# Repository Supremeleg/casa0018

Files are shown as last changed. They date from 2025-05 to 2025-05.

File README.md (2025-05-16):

# GlyphWand – TinyML Gesture Recognition Wand
This project uses a simple magic wand to write ‘magic spells’ in the air to control the colour and brightness of the light strips of a smart cabin clock simulated by LEGO.
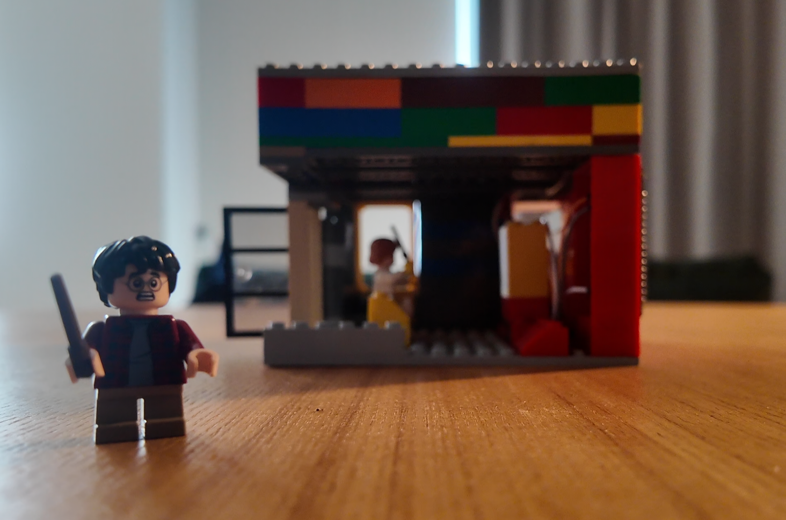
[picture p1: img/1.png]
Wand in action
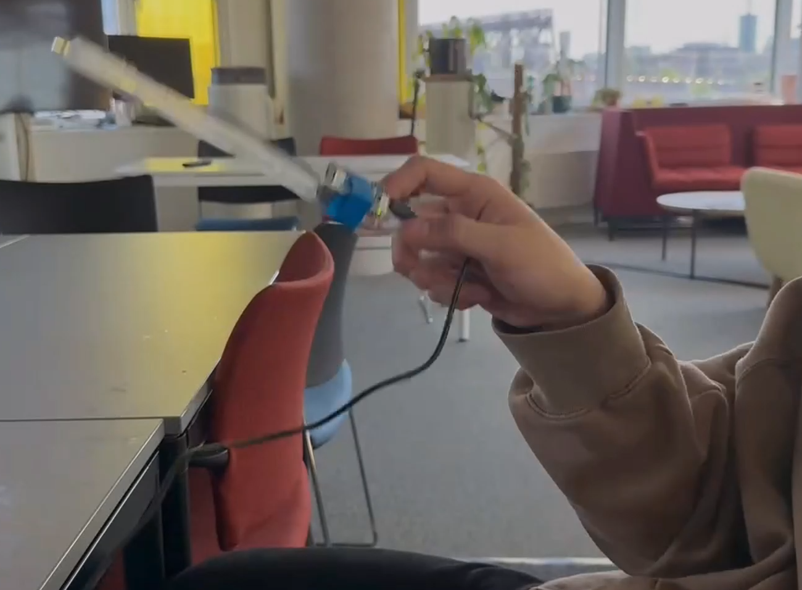
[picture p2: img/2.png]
Live classification stream
    
Watch demo video: https://youtu.be/_tfvsXkmZEY

---

## Features & Workflow
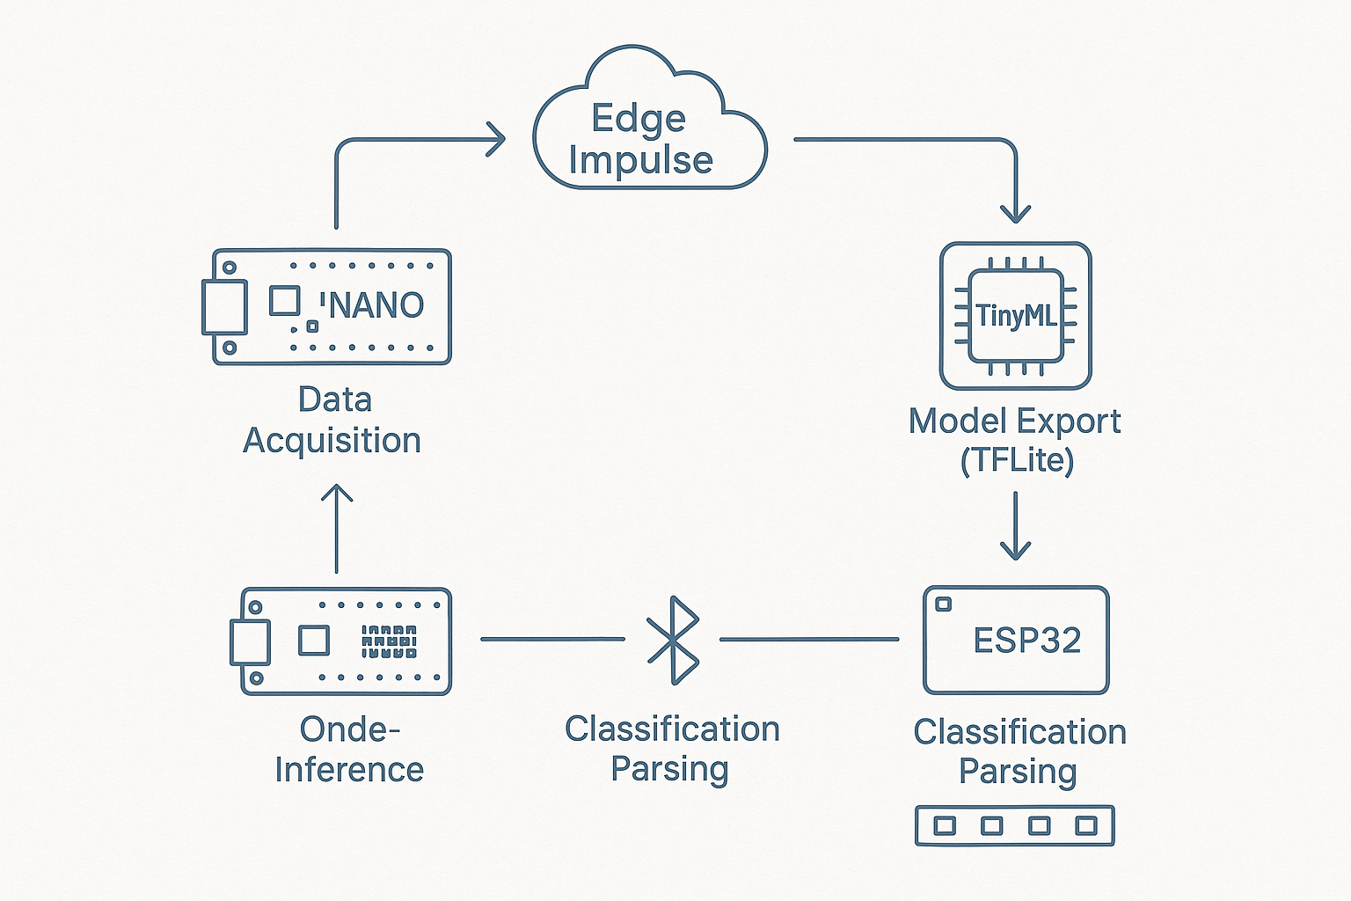
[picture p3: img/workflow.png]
Workflow


Real-time air-gesture recognition on an **Arduino Nano 33 BLE Sense**, transmitting the result over Bluetooth to an **ESP32** that drives an addressable LED strip.

* **Multi‑gesture recognition** – circles, waves, diagonals, and air‑written letters **A, B, C, D**  

* **Ultra‑light 1‑D CNN** (Conv 16×5 → Conv 32×3 → FC 64) quantised to **INT8**  
* **Edge Impulse** end‑to‑end workflow (data → DSP → model → deployment)  
* **Bluetooth LE** messaging to an ESP32; LED strip reacts with configurable light scenes  

---

## Demo
| Wand in action | Image | Raw Data Samples |
|---|---|---|
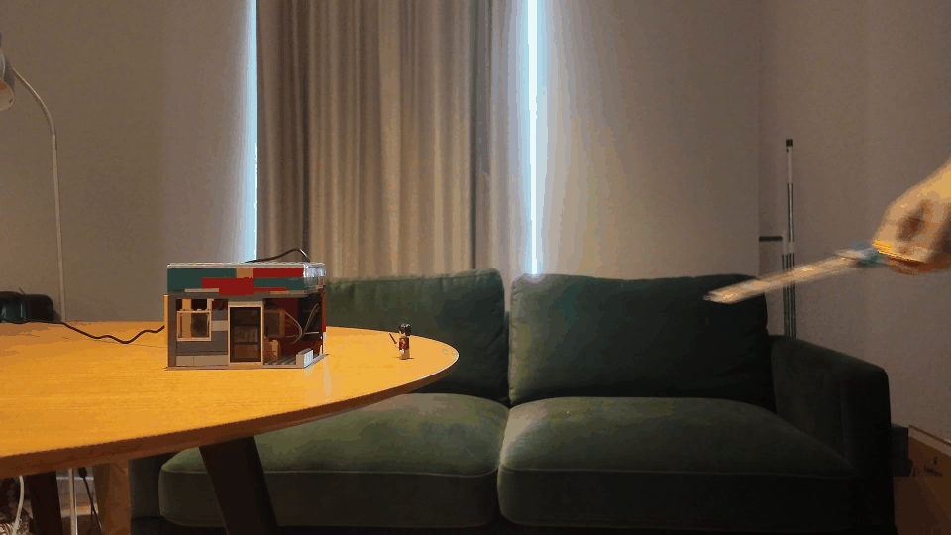
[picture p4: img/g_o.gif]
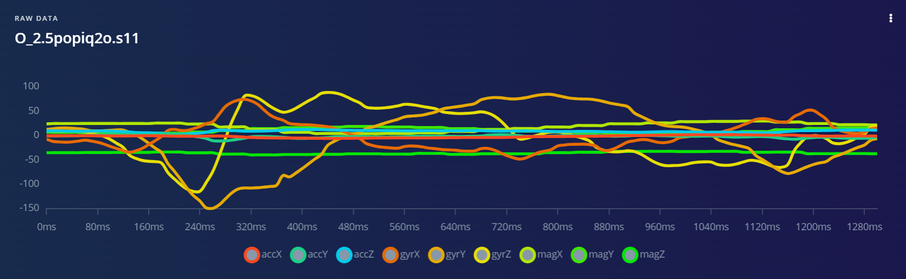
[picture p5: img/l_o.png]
| "O" |  |||---|---|---|
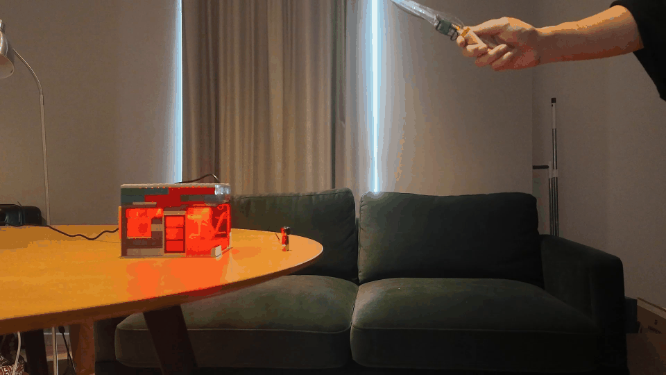
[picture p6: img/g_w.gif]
W gesture
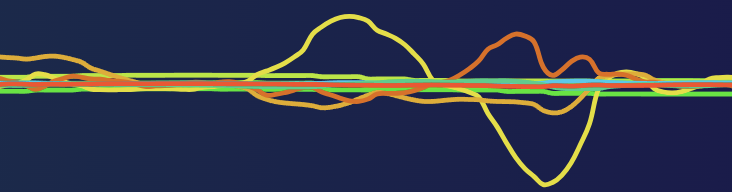
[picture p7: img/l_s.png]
| "W" |  |||---|---|---|
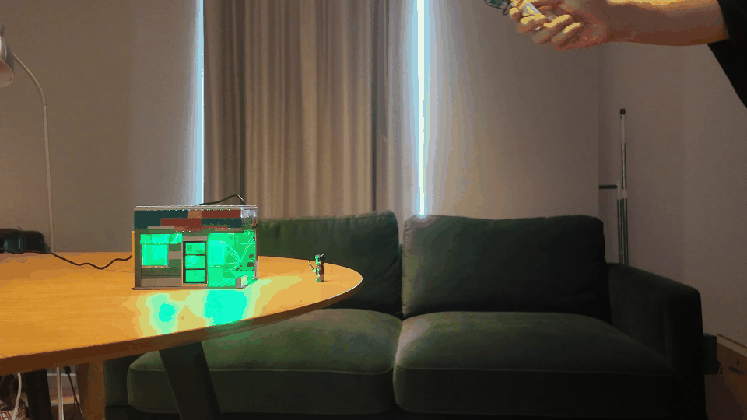
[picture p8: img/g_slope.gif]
Slope gesture
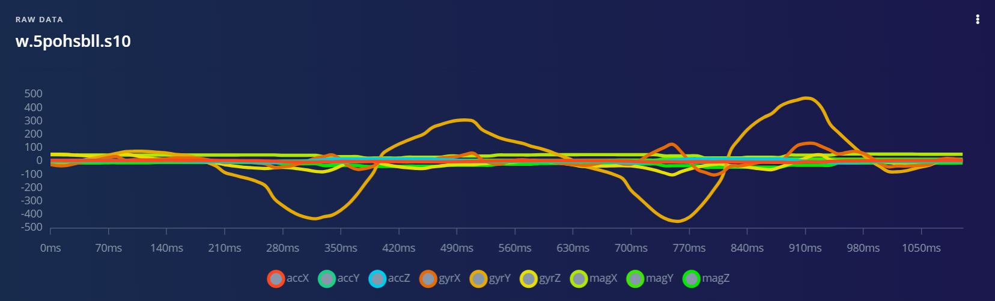
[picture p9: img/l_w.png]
| "Slope" |  |||---|---|---|
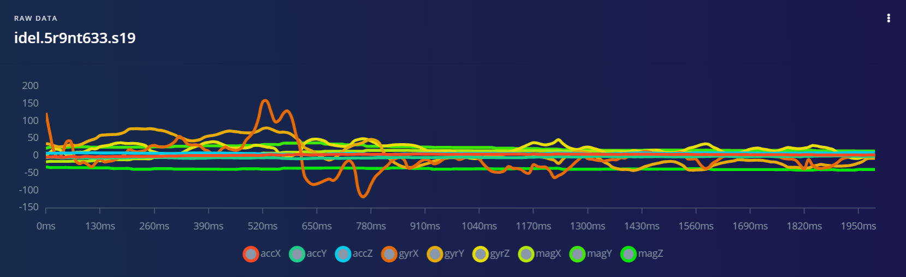
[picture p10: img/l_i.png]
i gesture
| "Idle" | ---||
---

## Hardware
| Part | Notes |
|---|---|
| **Arduino Nano 33 BLE Sense Kit** | 9‑axis IMU + nRF52840 BLE SoC |
| **ESP32 (DoIt DevKit V1)** | Receives BLE packets, drives LED strip |
| **WS2812B LED strip** | Any length; tested with 60 pixels |
| Li‑Po battery 3.7 V | ≥ 500 mAh recommended |

---

## Dataset
| Source | Classes | Samples | Rate | Window |
|---|---|---|---|---|
| **In‑house recordings** | O, W, Slope,  idle | 4 × ≈50 | 100 Hz | 2 s (200 frames) |

Initially, a gesture recognition system was developed using the Arduino Nano 33 BLE Sense. Three basic gestures—circular, wavy, and diagonal—were each performed approximately 50 times, sampled at a frequency of 100 Hz over a duration of 2 seconds, yielding approximately 200 three-axis accelerometer readings per trial while maintaining a fixed handle orientation. A compact model trained on this dataset achieved high accuracy.

The dataset is available for download here: [Glyphwand-export.zip](Dataset/Glyphwand-export.zip)

To expand the dataset, this project incorporated the publicly available IMU Alphabet Dataset from the Indian Institute of Technology and Boston University. This dataset comprises recordings from 124 volunteers, each writing 52 letters 50 times at a sampling frequency of 50 Hz, with sensors placed at varying positions on the pen tip, resulting in approximately 320,000 sequences. From this dataset, approximately 10,000 samples corresponding to the uppercase letters A–D were extracted and reformatted to match the structure of data sets produced independently in the project.

As it is not authorised to be shared here, you can find the original dataset at this link: https://ieee-dataport.org/documents/dataset-inertial-measurement-units-handwritten-english-alphabets-leveraging-diversity

---

## Quick Start
### 1 · Clone & install
```bash
git clone https://github.com/<your-username>/GlyphWand.git
cd GlyphWand
arduino-cli core install arduino:mbed_nano
pio pkg install   # if you prefer PlatformIO
```

### 2 · Flash the TinyML firmware
1. Open **`firmware/glyphwand.ino`** in the Arduino IDE.  
2. Follow the [Edge Impulse deployment guide](https://docs.edgeimpulse.com/docs) to  
   *a)* export the **Arduino library** of the trained model, and  
   *b)* drop the generated ZIP into `firmware/lib/`.  
3. Select *Arduino Nano 33 BLE Sense* and click **Upload**.

### 3 · Simple shell
1. Simple shells cut from dwg files:（You can either laser cut or cut 3mm cardboard）
   Download the shell design file here: [firstcut.dwg](Resources/firstcut.dwg)
2. Installing the Arduino Nano 33 BLE and battery

### 4 · ESP32 & LED 
1. Burning code for the ESP32
2. Wired ESP32 and LED strip
3. Connecting ESP32 and Arduino Nano 33 BLE Sense with Bluetooth

### 5 · Play!
* Wave the wand: the on‑board RGB LED shows the predicted label,  
  the LED strip mirrors it with magical effects ✨  

---

> *Made with ❤️ and a little magic.*

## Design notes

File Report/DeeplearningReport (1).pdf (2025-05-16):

# Report on Gesture Recognition Wand System Based on Arduino Nano 33 BLE Sense Board

Qijie Wang, https://github.com/Supremeleg/casa0018/https://studio.edgeimpulse.com/public/656098/live

## Introduction

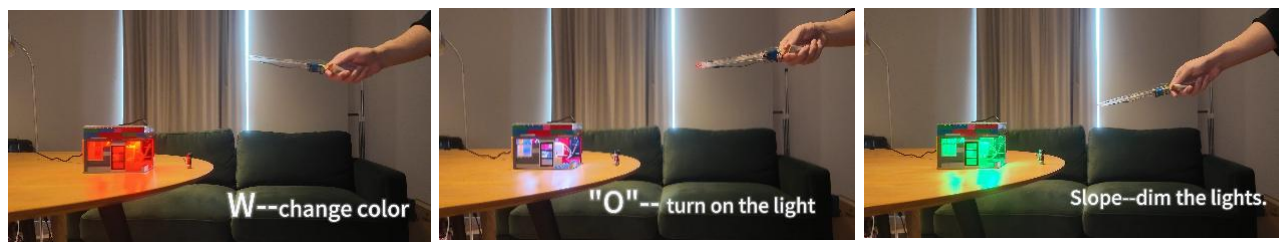
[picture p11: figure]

Developments in embedded machine learning (TinyML) enable gesture recognition on resource-constrained microcontrollers. (Gao,2019)

This project is based on the Arduino Nano 33 BLE Sense board(Arduino, 2024), using its on-board accelerometer to realise a ‘magic wand’ gesture control system. Users wave the handheld device to draw a specific trajectory to achieve the control of the LED strip, this interaction is full of fun and magic. （Shahizat, n.d.）

This project references the official TensorFlow Magic Wand example project, which uses a deep learning model to recognise three gestures on an Arduino: ‘Wing’, ‘Ring’, and ‘Slope’, and indicates the recognition results via LEDs. Based on the replication of this

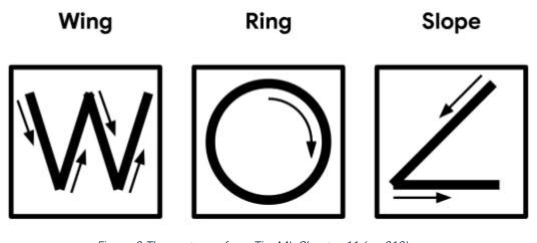
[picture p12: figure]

classic scheme, this project tries to extend the recognition of more complex letter

Figure 2 The gestures-from TinyML Chapter 11 (pp.313)

Figure 1 Project--GlyphWand gestures, and conducts a series of experimental adjustments to address the problems of insufficient data, model selection, and misrecognition encountered in the process, and iteratively improves the model performance. The motivation of the project is to explore the potential of TinyML in real-time gesture recognition, IoT control and interactive entertainment, and to provide practical experience in pattern recognition on resource-constrained devices.

## Research Question

- How can the gesture recognition model be effectively deployed on a resource-constrained microcontroller such as the Arduino Nano 33 BLE Sense while maintaining reliable performance?
- Considering the storage and computational limitations of embedded systems, which model architecture—fully connected networks, convolutional neural networks, or recurrent neural networks—is most suitable for achieving highaccuracy of gesture recognition within this project?

## Application Overview

The process of this project consists of five main parts: data acquisition, model training module, embedded reasoning, Bluetooth signal transmission, and LED strip response, and the overall architecture is shown as follows.

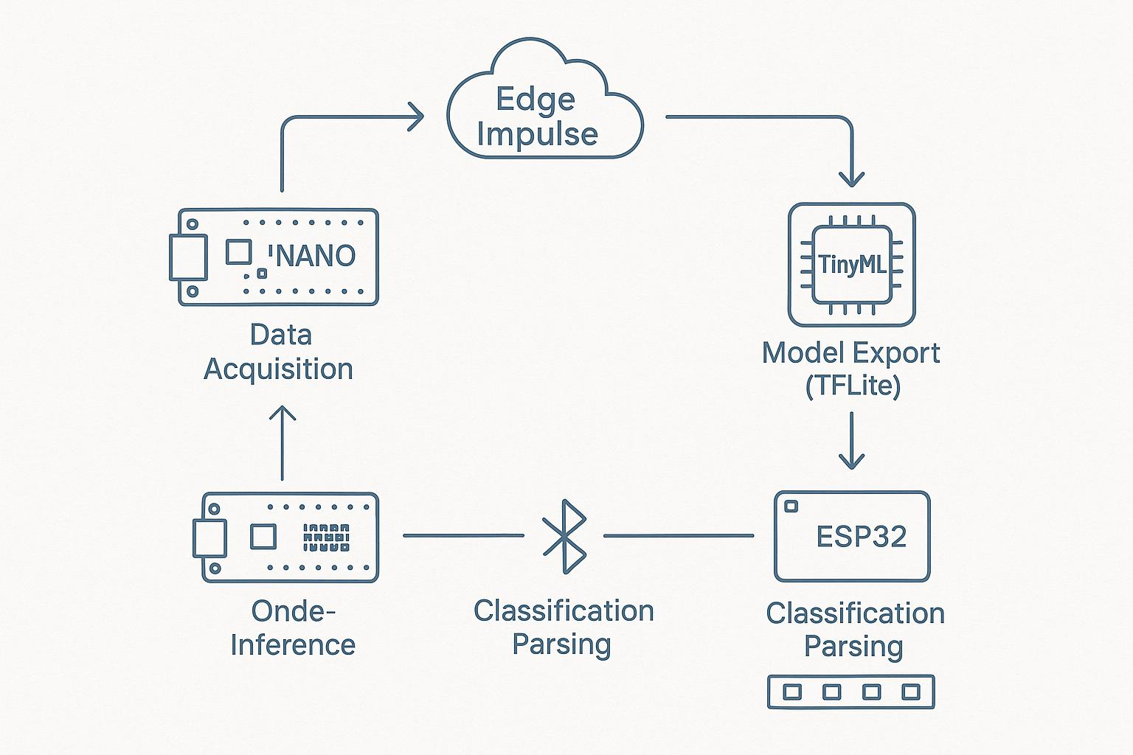
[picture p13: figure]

- In the data acquisition phase, the acceleration sensor that comes with the Arduino development board is used to acquire gesture motion data, and the data is uploaded and managed by the Edge Impulse platform for model training. Edge Impulse, as a one-stop solution, supports the whole process from sensor data acquisition to model generation(Edge Impulse, 2024), which accelerates the model development and deployment. deployment. The data forwarding tool uploads the real-time three-axis acceleration data collected by Arduino to the cloud, and labels the data according to the gesture category to build the data set for training.
- Subsequently, the signal processing flow and learning blocks are configured on the Edge Impulse platform, and the default neural network architecture is used to train the data to generate a preliminary gesture recognition model.
- Once training was complete, the generated TensorFlow Lite miniature model was exported and burned into the Arduino Nano 33 BLE Sense board. During the inference phase, the device continuously acquires new accelerometer data and performs real-time gesture classification with the locally deployed TinyML model.
- The results of the inference are sent to the ESP32 receiver via the Bluetooth module of the Arduino Nano 33 BLE Sense, and the ESP32 triggers the corresponding LED strip control logic based on the received classification results.
- In the end, the LED strip presents different light effect feedbacks according to the classification results to achieve the system response.

## Data Sets and Pre-Processing

### Self-collecting data sets:

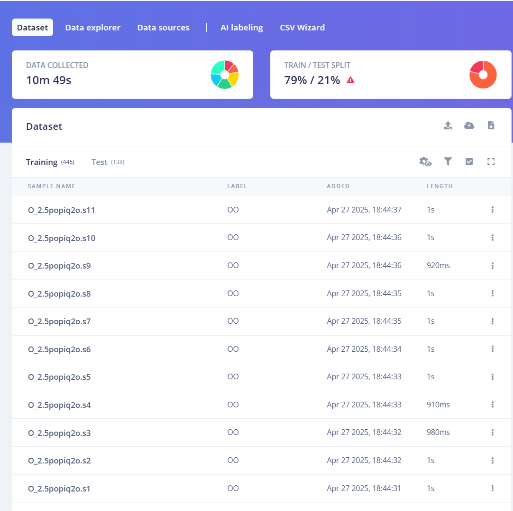
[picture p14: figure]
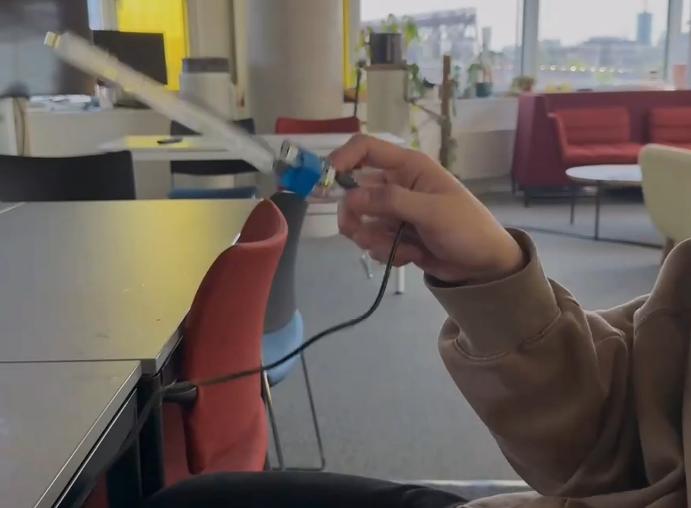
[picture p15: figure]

Initially, a gesture recognition system was developed using the Arduino Nano 33 BLE Sense. Three basic gestures—circular, wavy, and diagonal—were each performed approximately 50 times, sampled at a frequency of 100 Hz over a duration of 2 seconds, yielding approximately 200 three-axis accelerometer readings per trial while maintaining a fixed handle orientation. A compact model trained on this dataset achieved high accuracy.

Subsequently, four additional air-written letters (A–D) were introduced under the same experimental conditions, with approximately 50 trials per letter. The trajectories associated with these letters exhibited significantly greater variability, demanding

Figure 3 Data acquisition enhanced generalisation capability from the model.

### Public datasets:

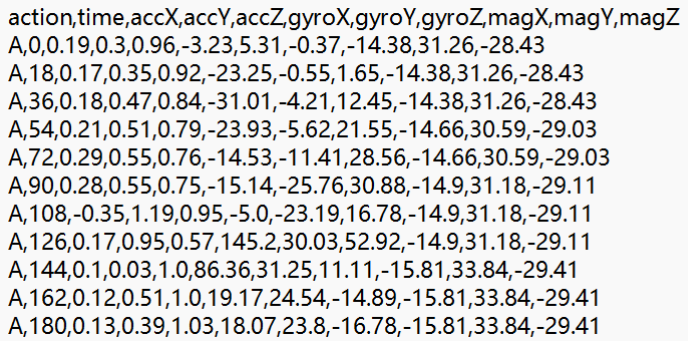
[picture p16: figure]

Figure 4 Dataset

To expand the dataset, this project incorporated the publicly available IMU Alphabet Dataset from the Indian Institute of Technology and Boston University. This dataset comprises recordings from 124 volunteers, each writing 52 letters 50 times at a sampling frequency of 50 Hz, with sensors placed at varying positions on the pen tip, resulting in approximately 320,000 sequences. From this dataset, approximately 10,000 samples corresponding to the uppercase letters A–D were extracted and reformatted to match the structure of data sets produced independently in the project. However, when evaluated on this external dataset, the model’s accuracy dropped to approximately 40%, compared to around 60% accuracy achieved on the self-collected dataset.

Three mismatches explain the decline:

- Sensor and sampling gaps—50 Hz, multi-sensor layout versus our single 100 Hz sensor.
- User diversity—height, writing angle and personal habits broadened trajectory variance.
- Model limits—capacity, regularisation and alignment were not scaled to the larger, more complex distribution.

Data relevance matters more than sheer size; adding mismatched samples can erode, not enhance, performance.

### Cleaning & Augmentation

Several preprocessing steps were applied to prepare the dataset for model training. All samples were standardised to a uniform window length of 200 frames through either zero-padding or trimming. Subsequently, min–max normalisation was performed to scale the data within the range of [-1, 1], and a five-point sliding-mean filter was applied to reduce high-frequency noise.

Online data augmentation techniques were employed during training to enhance model robustness. Specifically, 20 dB Gaussian noise was injected with a probability of 0.5, and temporal warping within a ±10% range was applied with a probability of 0.3.

Augmentation of stillness samples proved critical: idle devices exhibited a false trigger rate of approximately 18% without augmentation. Incorporating stillness augmentation reduced the false positive rate to below 2%, significantly improving model reliability under static conditions.

## Model Architecture Exploration

By default, Edge Impulse starts with a lightweight MLP: the input layer is connected to a feature expansion vector, followed by two layers of 10-20 ReLU hidden neurons each, and finally a softmax output layer (initially 3 classes and then expanded to 4 classes). The parameters are very few, which makes it easy to deploy with micro-control. When trained with the default hyperparameters (30 epoch, learning rate 0.0005), the validation accuracy was close to 100 %, but this was mostly due to overfitting because of the small and homogeneous samples - the model remembers a specific user's trajectory. With the addition of more complex letter gestures, the simple MLP was unable to capture the temporal features and the accuracy rapidly declined.

Iterative Improvement of Model Architectures: Given that gesture data are essentially time-series signals, Plural model architectures suitable for time series data were tried, and their effectiveness was compared:

Model | Params FLASH (kB)

Test
Acc.(%)

F1-
score

Notes

2-layer MLP (128–64) 1.9 k | 11 | 90.1 | 0.90 | Low latency but
prone to over-fit.

1D-CNN (Conv16-5
+ Conv32-3 + FC64)
| 5.1 k | 19 | 94.5 | 0.94 | Best size-accuracy trade-off.
GRU-20 | 6.3 k | 24 | 92.8 | 0.92 | Slower; slight gain on letters.
LSTM-20 | 8.4 k | 30 | 94.9 | 0.95 | Highest accuracy but

A hybrid Conv+LSTM exceeded 35 kB and was abandoned. The final deployment therefore uses the highlighted 1D-CNN.

## Experiments

Stationary-class ablation
Without “no-gesture” data, the CNN often mistook sensor noise during idle periods for the last-seen gesture. It added ≈200 stationary/ random-wiggle clips—matching the gesture count to keep classes balanced—and retrained. The revised model recognised idle states with 98 % accuracy, while the three gesture classes lost only ~1 pp in accuracy. Thus, negative samples sharply cut false triggers at almost no cost to gesture performance, so the stationary class is kept as a standard category in all subsequent experiments.

Should Clockwise (O₁) and Counter-clockwise (O₂) Circles Be Separate Classes?

Scenario Label
Configuration

Train / Test
Samples (O₁
/ O₂)

Test
Accuracy

Weighted
F₁

Main
Confusion
A – | O = O₁ + O₂, W, | 176 / 44 | 95.1 % | 0.95 | —
Merged | Slope, Uncertain | (merged)
B – Split | O₁, O₂, W, Slope,
Uncertain
88 / 88 | 79.5 % | 0.85 | 12 – 24 % O₁ ↔ O₂

Using the same two-layer MLP (40→20 ReLU, 40 epochs, lr = 5 × 10⁻⁴, INT8 quantised), I compared treating clockwise and counter-clockwise circles as a single class (Scenario
A) versus separate classes (Scenario B). With only 110 recordings per direction (two subjects, 55 each), merging the trajectories delivered markedly better performance— 95.1 % accuracy and F₁ = 0.95—while splitting them caused heavy mutual confusion and a 15 pp accuracy drop. The result suggests that, at this data scale and model capacity, circle direction is not a reliable discriminative feature; keeping both directions under one O label is the preferable strategy unless a larger, more diverse dataset or a highercapacity time-series model is introduced.

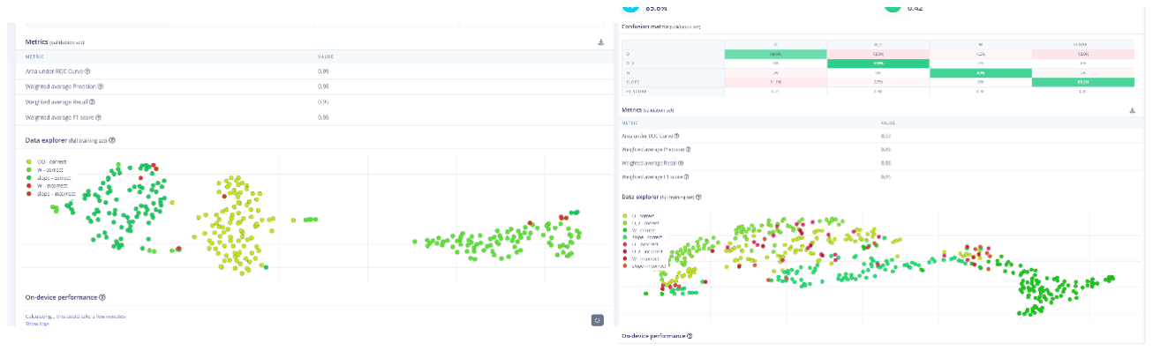
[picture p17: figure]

## Results and Observations

The iterative experiments confirmed that a compact 1-D convolutional network strikes the best balance between accuracy, latency and on-device footprint for the Nano 33 BLE Sense. After hyper-parameter tuning (Conv 16 × 5, Conv 32 × 3, FC 64, ReLU, dropout 0.2), the model occupied 19 kB of flash and 8 kB of RAM, well below the board’ s 1 MB/256 kB ceilings. Average inference time measured with micros() was 3.4 ms, leaving >99 % of the 100 Hz sampling window free for other tasks.

On the in-house test set (three simple gestures + letters A–D + idle), the CNN achieved 94.5 % overall accuracy and an F1-score of 0.94. Confusion matrices revealed that circle vs. letter “O” style trajectories caused the majority of residual errors; other misclassifications were evenly distributed. Introducing the “stationary” class cut false trigger rate from 18 % to 1.7 % while reducing gesture accuracy by only 0.9 pp, validating the value of explicit negative samples.

Future improvements

- Larger and more diverse data: Collect additional user traces (different hand sizes, writing speeds and orientations) and augment with synthetic trajectories to improve generalisation, especially on visually similar patterns such as circles vs. the letter “O”.
- Model compression experiments: Compare INT8 quantisation, weight pruning and knowledge-distillation to push the footprint even lower and reduce power draw.
- Adaptive on-device learning: Explore lightweight continual-learning or calibration routines so the wand can fine-tune to a new user in seconds without cloud retraining.
- Sensor fusion: Add the board’s gyroscope or an external time-of-flight sensor to capture rotational cues and depth, potentially resolving remaining ambiguities between complex letters.
- Edge-to-cloud feedback loop: Log mis-classifications during real-world use, upload them opportunistically, and retrain periodically to keep the model current.

## Bibliography

1. TensorFlow (2020) Magic Wand Example – TensorFlow Lite for Microcontrollers. GitHub repository. Available at: https://github.com/tensorflow/tensorflow/tree/master/tensorflow/lite/micro/examples/magic_wand (https://github.com/tensorflow/tensorflow/tree/master/tensorflow/lite/micro/examples/magic_wand) (Accessed: 29 April 2025).
2. Gao, S. (2019) ‘Harry Potter Magic Wand’. Hackster.io, 14 August. Available at: https://www.hackster.io/sibo_gao/harry-potter-magic-wand-384477 (Accessed: 29 April 2025).
3. Shahizat (n.d.) ‘Gesture Recognition Using Raspberry Pi Pico and Edge Impulse’. Instructables. Available at: https://www.instructables.com/Gesture-Recognition-Using-Raspberry-Pi-Pico-and-Ed/ (https://www.instructables.com/Gesture-Recognition-Using-Raspberry-Pi-Pico-and-Ed/) (Accessed: 29 April 2025).
4. Edge Impulse (2024) Edge Impulse Documentation: Getting Started. Edge Impulse Docs. Available at: https://docs.edgeimpulse.com/docs (Accessed: 29 April 2025).
5. Arduino (2024) Nano 33 BLE Sense — Product Documentation. Arduino.cc. Available at: https://www.arduino.cc/en/Guide/NANO33BLESense (Accessed: 29 April 2025).

## Declaration of Authorship

I, Qijie Wang, confirm that the work presented in this assessment is my own. Where information has been derived from other sources, I confirm that this has been indicated in the work.

Qijie Wang

ASSESSMENT DATE 04/29/2025

Word count: 1644

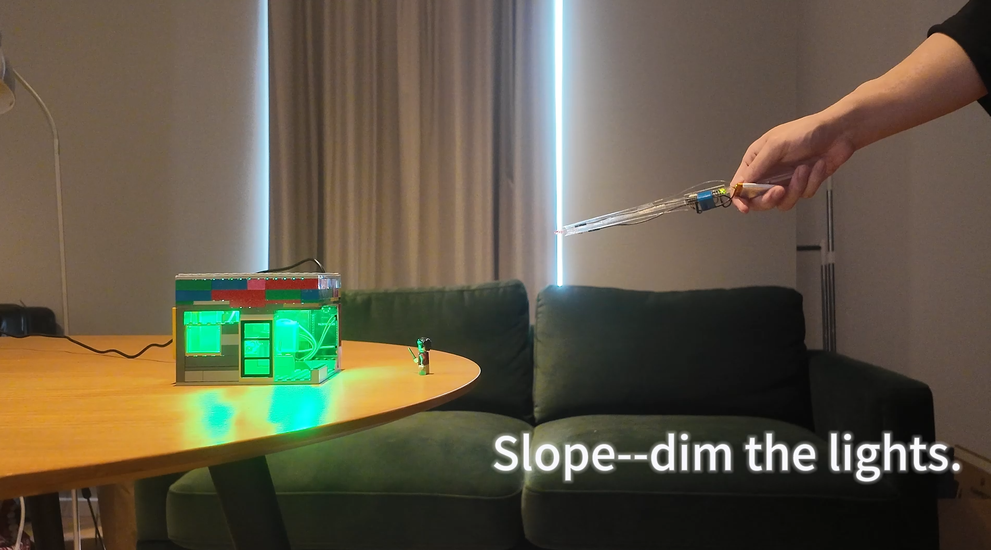
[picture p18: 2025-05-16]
img/S.png

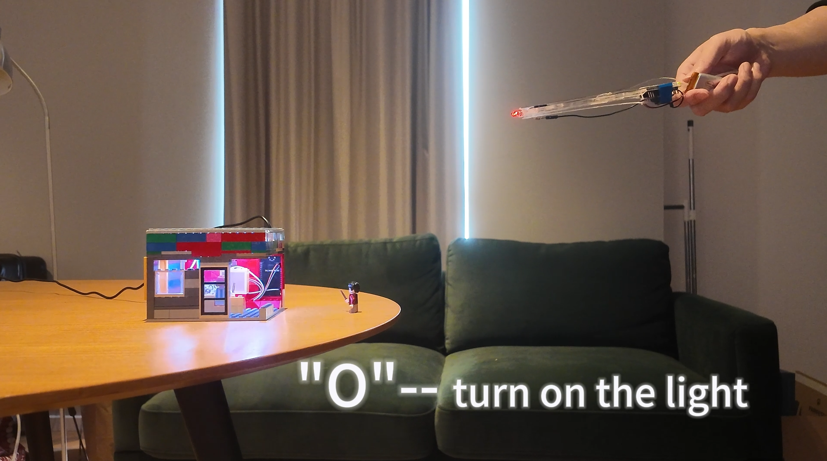
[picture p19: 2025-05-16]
img/O.png

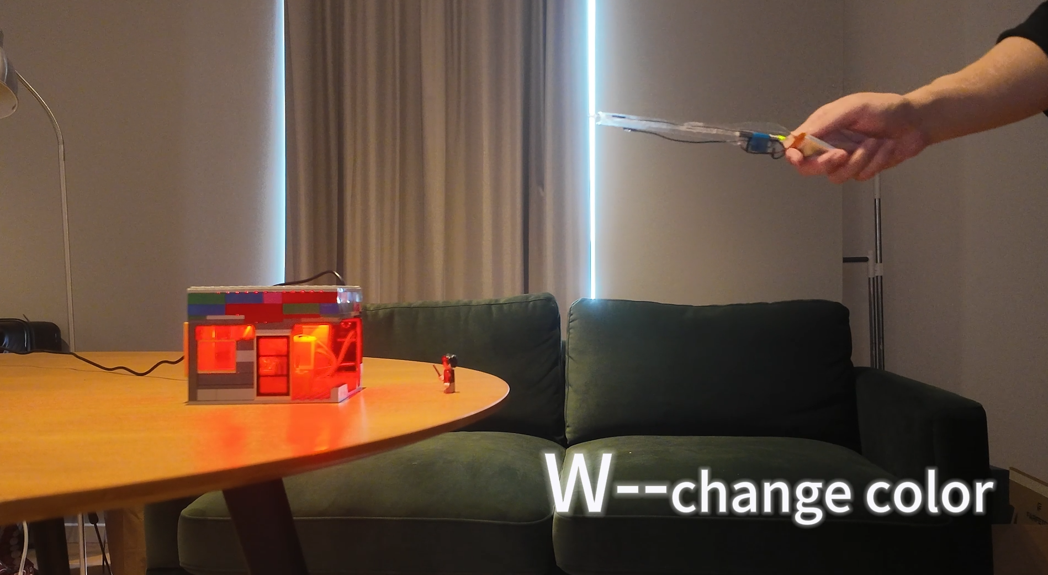
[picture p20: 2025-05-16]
img/W.png

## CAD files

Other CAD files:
Resouces/firstcut.dwg
Resouces/first_cut.3dm

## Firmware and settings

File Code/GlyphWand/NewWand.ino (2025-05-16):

/* Edge Impulse ingestion SDK
 * Copyright (c) 2022 EdgeImpulse Inc.
 *
 * Licensed under the Apache License, Version 2.0 (the "License");
 * you may not use this file except in compliance with the License.
 * You may obtain a copy of the License at
 * http://www.apache.org/licenses/LICENSE-2.0
 *
 * Unless required by applicable law or agreed to in writing, software
 * distributed under the License is distributed on an "AS IS" BASIS,
 * WITHOUT WARRANTIES OR CONDITIONS OF ANY KIND, either express or implied.
 * See the License for the specific language governing permissions and
 * limitations under the License.
 *
 */

/* Includes ---------------------------------------------------------------- */
#include <SupremeWand_inferencing.h>
#include <Arduino_LSM9DS1.h> //Click here to get the library: https://www.arduino.cc/reference/en/libraries/arduino_lsm9ds1/
#include <Arduino_LPS22HB.h> //Click here to get the library: https://www.arduino.cc/reference/en/libraries/arduino_lps22hb/
#include <Arduino_HTS221.h> //Click here to get the library: https://www.arduino.cc/reference/en/libraries/arduino_hts221/
#include <Arduino_APDS9960.h> //Click here to get the library: https://www.arduino.cc/reference/en/libraries/arduino_apds9960/
#include <ArduinoBLE.h>

// BLE配置
#define BLE_DEVICE_NAME "WandBLE"
#define BLE_SERVICE_UUID "19B10000-E8F2-537E-4F6C-D104768A1214"
#define BLE_CHARACTERISTIC_UUID "19B10001-E8F2-537E-4F6C-D104768A1214"

// BLE服务
BLEService wandService(BLE_SERVICE_UUID);
BLEStringCharacteristic actionCharacteristic(BLE_CHARACTERISTIC_UUID, BLEWrite | BLENotify, 20);

enum sensor_status {
    NOT_USED = -1,
    NOT_INIT,
    INIT,
    SAMPLED
};

/** Struct to link sensor axis name to sensor value function */
typedef struct{
    const char *name;
    float *value;
    uint8_t (*poll_sensor)(void);
    bool (*init_sensor)(void);    
    sensor_status status;
} eiSensors;

/* Constant defines -------------------------------------------------------- */
#define CONVERT_G_TO_MS2    9.80665f

/**
 * When data is collected by the Edge Impulse Arduino Nano 33 BLE Sense
 * firmware, it is limited to a 2G range. If the model was created with a
 * different sample range, modify this constant to match the input values.
 * See https://github.com/edgeimpulse/firmware-arduino-nano-33-ble-sense/blob/master/src/sensors/ei_lsm9ds1.cpp
 * for more information.
 */
#define MAX_ACCEPTED_RANGE  2.0f

/** Number sensor axes used */
#define N_SENSORS     18

#define TRIGGER_THRESHOLD 4.0f  // 触发阈值，调高减少误触发
#define CLOSE_THRESHOLD (TRIGGER_THRESHOLD * 0.8f) // 关闭时更容易触发
#define TRIGGER_WINDOW 3000      // 触发窗口时间（2秒）
#define LED_PIN 13               // LED引脚
#define DEBUG_INTERVAL 500       // 调试信息打印间隔（毫秒）

bool is_recording = false;
bool waiting_for_second_trigger = false;
bool ready_for_next_trigger = true; // 新增，边沿检测
unsigned long last_trigger_time = 0;
float last_acc_magnitude = 0;
unsigned long last_debug_time = 0;
unsigned long last_action_time = 0; // 上一次打印Action的时间

/* Forward declarations ------------------------------------------------------- */
float ei_get_sign(float number);

bool init_IMU(void);
bool init_HTS(void);
bool init_BARO(void);
bool init_APDS(void);

uint8_t poll_acc(void);
uint8_t poll_gyr(void);
uint8_t poll_mag(void);
uint8_t poll_HTS(void);
uint8_t poll_BARO(void);
uint8_t poll_APDS_color(void);
uint8_t poll_APDS_proximity(void);
uint8_t poll_APDS_gesture(void);

/* Private variables ------------------------------------------------------- */
static const bool debug_nn = false; // Set this to true to see e.g. features generated from the raw signal

static float data[N_SENSORS];
static bool ei_connect_fusion_list(const char *input_list);

static int8_t fusion_sensors[N_SENSORS];
static int fusion_ix = 0;

/** Used sensors value function connected to label name */
eiSensors sensors[] =
{
    "accX", &data[0], &poll_acc, &init_IMU, NOT_USED,
    "accY", &data[1], &poll_acc, &init_IMU, NOT_USED,
    "accZ", &data[2], &poll_acc, &init_IMU, NOT_USED,
    "gyrX", &data[3], &poll_gyr, &init_IMU, NOT_USED,
    "gyrY", &data[4], &poll_gyr, &init_IMU, NOT_USED,
    "gyrZ", &data[5], &poll_gyr, &init_IMU, NOT_USED,
    "magX", &data[6], &poll_mag, &init_IMU, NOT_USED,
    "magY", &data[7], &poll_mag, &init_IMU, NOT_USED,
    "magZ", &data[8], &poll_mag, &init_IMU, NOT_USED,

    "temperature", &data[9], &poll_HTS, &init_HTS, NOT_USED,
    "humidity", &data[10], &poll_HTS, &init_HTS, NOT_USED,

    "pressure", &data[11], &poll_BARO, &init_BARO, NOT_USED,

    "red", &data[12], &poll_APDS_color, &init_APDS, NOT_USED,
    "green", &data[13], &poll_APDS_color, &init_APDS, NOT_USED,
    "blue", &data[14], &poll_APDS_color, &init_APDS, NOT_USED,
    "brightness", &data[15], &poll_APDS_color, &init_APDS, NOT_USED,
    "proximity", &data[16], &poll_APDS_proximity, &init_APDS, NOT_USED,
    "gesture", &data[17], &poll_APDS_gesture,&init_APDS, NOT_USED,
};

/**
* @brief      Arduino setup function
*/
void setup()
{
    /* Init serial */
    Serial.begin(115200);
    // comment out the below line to cancel the wait for USB connection (needed for native USB)
    //while (!Serial);
    Serial.println("Edge Impulse Sensor Fusion Inference\r\n");

    /* 初始化LED引脚 */
    pinMode(LED_PIN, OUTPUT);
    digitalWrite(LED_PIN, LOW);

    // 初始化BLE
    if (!BLE.begin()) {
        Serial.println("BLE初始化失败！");
        while (1);
    }

    // 设置BLE设备名称
    BLE.setLocalName(BLE_DEVICE_NAME);
    BLE.setAdvertisedService(wandService);
    
    // 添加特征
    wandService.addCharacteristic(actionCharacteristic);
    BLE.addService(wandService);
    
    // 开始广播
    BLE.advertise();
    Serial.println("BLE设备已启动，等待连接...");

    /* Connect used sensors */
    if(ei_connect_fusion_list(EI_CLASSIFIER_FUSION_AXES_STRING) == false) {
        ei_printf("ERR: Errors in sensor list detected\r\n");
        return;
    }

    /* Init & start sensors */
    for(int i = 0; i < fusion_ix; i++) {
        if (sensors[fusion_sensors[i]].status == NOT_INIT) {
            sensors[fusion_sensors[i]].status = (sensor_status)sensors[fusion_sensors[i]].init_sensor();
            if (!sensors[fusion_sensors[i]].status) {
              ei_printf("%s axis sensor initialization failed.\r\n", sensors[fusion_sensors[i]].name);             
            }
            else {
              ei_printf("%s axis sensor initialization successful.\r\n", sensors[fusion_sensors[i]].name);
            }
        }
    }
}

/**
* @brief      Get data and run inferencing
*/
void loop()
{
    // 处理BLE连接
    BLE.poll();

    // 主动采集一次加速度数据
    IMU.readAcceleration(data[0], data[1], data[2]);
    // 计算当前加速度的幅度
    float acc_magnitude = sqrt(data[0]*data[0] + data[1]*data[1] + data[2]*data[2]);

    // 调试用，打印当前状态
    //ei_printf("acc=%.2f, is_recording=%d, ready=%d\n", acc_magnitude, is_recording, ready_for_next_trigger);

    // 第一次超过阈值，进入识别模式
    if (acc_magnitude > TRIGGER_THRESHOLD && !is_recording && ready_for_next_trigger) {
        is_recording = true;
        waiting_for_second_trigger = true;
        ready_for_next_trigger = false;
        digitalWrite(LED_PIN, HIGH);  // 点亮LED
        ei_printf("\n开始识别手势...\r\n");
    }
    // 第二次超过关闭阈值，退出识别模式
    else if (acc_magnitude > CLOSE_THRESHOLD && is_recording && waiting_for_second_trigger && ready_for_next_trigger) {
        is_recording = false;
        waiting_for_second_trigger = false;
        ready_for_next_trigger = false;
        digitalWrite(LED_PIN, LOW);   // 关闭LED
        ei_printf("手势识别结束\r\n");
    }
    // 只要加速度低于关闭阈值，就允许下一次触发
    if (acc_magnitude < CLOSE_THRESHOLD) {
        ready_for_next_trigger = true;
    }
    
    // 只在记录状态下进行推理
    if (is_recording) {
        if (EI_CLASSIFIER_RAW_SAMPLES_PER_FRAME != fusion_ix) {
            ei_printf("ERR: Sensors don't match the sensors required in the model\r\n"
            "Following sensors are required: %s\r\n", EI_CLASSIFIER_FUSION_AXES_STRING);
            return;
        }

        ei_printf("Sampling...\r\n");

        // 分配缓冲区
        float buffer[EI_CLASSIFIER_DSP_INPUT_FRAME_SIZE] = { 0 };

        for (size_t ix = 0; ix < EI_CLASSIFIER_DSP_INPUT_FRAME_SIZE; ix += EI_CLASSIFIER_RAW_SAMPLES_PER_FRAME) {
            int64_t next_tick = (int64_t)micros() + ((int64_t)EI_CLASSIFIER_INTERVAL_MS * 1000);

            for(int i = 0; i < fusion_ix; i++) {
                if (sensors[fusion_sensors[i]].status == INIT) {
                    sensors[fusion_sensors[i]].poll_sensor();
                    sensors[fusion_sensors[i]].status = SAMPLED;
                }
                if (sensors[fusion_sensors[i]].status == SAMPLED) {
                    buffer[ix + i] = *sensors[fusion_sensors[i]].value;
                    sensors[fusion_sensors[i]].status = INIT;
                }
            }

            int64_t wait_time = next_tick - (int64_t)micros();
            if(wait_time > 0) {
                delayMicroseconds(wait_time);
            }
        }

        // 进行推理
        signal_t signal;
        int err = numpy::signal_from_buffer(buffer, EI_CLASSIFIER_DSP_INPUT_FRAME_SIZE, &signal);
        if (err != 0) {
            ei_printf("ERR:(%d)\r\n", err);
            return;
        }

        ei_impulse_result_t result = { 0 };
        err = run_classifier(&signal, &result, debug_nn);
        if (err != EI_IMPULSE_OK) {
            ei_printf("ERR:(%d)\r\n", err);
            return;
        }

        // 打印预测结果
        ei_printf("Predictions (DSP: %d ms., Classification: %d ms., Anomaly: %d ms.):\r\n",
            result.timing.dsp, result.timing.classification, result.timing.anomaly);
        float max_value = 0.0f;
        const char* max_label = NULL;
        for (size_t ix = 0; ix < EI_CLASSIFIER_LABEL_COUNT; ix++) {
            ei_printf("%s: %.5f\r\n", result.classification[ix].label, result.classification[ix].value);
            if (result.classification[ix].value > max_value) {
                max_value = result.classification[ix].value;
                max_label = result.classification[ix].label;
            }
        }
        if (max_label != NULL && String(max_label) != "none" && String(max_label) != "still") {
            if (millis() - last_action_time > 3000) {
                ei_printf("Action:%s\r\n", max_label);
                // 通过BLE发送数据
                if (actionCharacteristic.subscribed()) {
                    actionCharacteristic.writeValue(max_label);
                    Serial.print("Sent via BLE: ");
                    Serial.println(max_label);
                }
                last_action_time = millis();
            }
        }
        #if EI_CLASSIFIER_HAS_ANOMALY == 1
            ei_printf("    anomaly score: %.3f\r\n", result.anomaly);
        #endif
    }
    
    // 更新上一次的加速度值
    last_acc_magnitude = acc_magnitude;
}

#if !defined(EI_CLASSIFIER_SENSOR) || (EI_CLASSIFIER_SENSOR != EI_CLASSIFIER_SENSOR_FUSION && EI_CLASSIFIER_SENSOR != EI_CLASSIFIER_SENSOR_ACCELEROMETER)
#error "Invalid model for current sensor"
#endif


/**
 * @brief Go through sensor list to find matching axis name
 *
 * @param axis_name
 * @return int8_t index in sensor list, -1 if axis name is not found
 */
static int8_t ei_find_axis(char *axis_name)
{
    int ix;
    for(ix = 0; ix < N_SENSORS; ix++) {
        if(strstr(axis_name, sensors[ix].name)) {
            return ix;
        }
    }
    return -1;
}

/**
 * @brief Check if requested input list is valid sensor fusion, create sensor buffer
 *
 * @param[in]  input_list      Axes list to sample (ie. "accX + gyrY + magZ")
 * @retval  false if invalid sensor_list
 */
static bool ei_connect_fusion_list(const char *input_list)
{
    char *buff;
    bool is_fusion = false;

    /* Copy const string in heap mem */
    char *input_string = (char *)ei_malloc(strlen(input_list) + 1);
    if (input_string == NULL) {
        return false;
    }
    memset(input_string, 0, strlen(input_list) + 1);
    strncpy(input_string, input_list, strlen(input_list));

    /* Clear fusion sensor list */
    memset(fusion_sensors, 0, N_SENSORS);
    fusion_ix = 0;

    buff = strtok(input_string, "+");

    while (buff != NULL) { /* Run through buffer */
        int8_t found_axis = 0;

        is_fusion = false;
        found_axis = ei_find_axis(buff);

        if(found_axis >= 0) {
            if(fusion_ix < N_SENSORS) {
                fusion_sensors[fusion_ix++] = found_axis;
                sensors[found_axis].status = NOT_INIT;
            }
            is_fusion = true;
        }

        buff = strtok(NULL, "+ ");
    }

    ei_free(input_string);

    return is_fusion;
}

/**
 * @brief Return the sign of the number
 * 
 * @param number 
 * @return int 1 if positive (or 0) -1 if negative
 */
float ei_get_sign(float number) {
    return (number >= 0.0) ? 1.0 : -1.0;
}

bool init_IMU(void) {
  static bool init_status = false;
  if (!init_status) {
    init_status = IMU.begin();
  }
  return init_status;
}

bool init_HTS(void) {
  static bool init_status = false;
  if (!init_status) {
    init_status = HTS.begin();
  }
  return init_status;
}

bool init_BARO(void) {
  static bool init_status = false;
  if (!init_status) {
    init_status = BARO.begin();
  }
  return init_status;
}

bool init_APDS(void) {
  static bool init_status = false;
  if (!init_status) {
    init_status = APDS.begin();
  }
  return init_status;
}

uint8_t poll_acc(void) {
  
    if (IMU.accelerationAvailable()) {

    IMU.readAcceleration(data[0], data[1], data[2]);

    for (int i = 0; i < 3; i++) {
        if (fabs(data[i]) > MAX_ACCEPTED_RANGE) {
            data[i] = ei_get_sign(data[i]) * MAX_ACCEPTED_RANGE;
        }
    }

    data[0] *= CONVERT_G_TO_MS2;
    data[1] *= CONVERT_G_TO_MS2;
    data[2] *= CONVERT_G_TO_MS2;
    }

    return 0;
}

uint8_t poll_gyr(void) {
  
    if (IMU.gyroscopeAvailable()) {
        IMU.readGyroscope(data[3], data[4], data[5]);
    }
    return 0;
}

uint8_t poll_mag(void) {
  
    if (IMU.magneticFieldAvailable()) {
        IMU.readMagneticField(data[6], data[7], data[8]);
    }
    return 0;
}

uint8_t poll_HTS(void) {
  
    data[9] = HTS.readTemperature();
    data[10] = HTS.readHumidity();
    return 0;
}

uint8_t poll_BARO(void) {
  
    data[11] = BARO.readPressure(); // (PSI/MILLIBAR/KILOPASCAL) default kPa
    return 0;
}

uint8_t poll_APDS_color(void) {
  
    int temp_data[4];
    if (APDS.colorAvailable()) {
        APDS.readColor(temp_data[0], temp_data[1], temp_data[2], temp_data[3]);

        data[12] = temp_data[0];
        data[13] = temp_data[1];
        data[14] = temp_data[2];
        data[15] = temp_data[3];
    }
}

uint8_t poll_APDS_proximity(void) {

    if (APDS.proximityAvailable()) {
        data[16] = (float)APDS.readProximity();
    }
    return 0;
}

uint8_t poll_APDS_gesture(void) {
    if (APDS.gestureAvailable()) {
        data[17] = (float)APDS.readGesture();
    }
    return 0;
}

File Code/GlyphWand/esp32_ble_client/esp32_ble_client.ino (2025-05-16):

#include <BLEDevice.h>
#include <BLEUtils.h>
#include <BLEScan.h>
#include <BLEClient.h>
#include <BLEAdvertisedDevice.h>
#include <Adafruit_NeoPixel.h>

#define LED_PIN    22
#define NUM_LEDS   46

#define SERVICE_UUID        "19B10000-E8F2-537E-4F6C-D104768A1214"
#define CHARACTERISTIC_UUID "19B10001-E8F2-537E-4F6C-D104768A1214"
#define TARGET_NAME         "WandBLE"

Adafruit_NeoPixel strip(NUM_LEDS, LED_PIN, NEO_GRB + NEO_KHZ800);

static BLEAdvertisedDevice* myDevice = nullptr;
static BLERemoteCharacteristic* pRemoteCharacteristic = nullptr;
static bool doConnect = false;
static bool connected = false;

// 灯带状态
bool led_on = false;
uint8_t color_mode = 0; // 0:白 1:红 2:绿 3:蓝 4:黄
uint8_t brightness_mode = 1; // 0:低 1:中 2:高

const uint8_t brightness_table[3] = {30, 100, 255};
const uint32_t color_table[5] = {
  strip.Color(255,255,255), // 白
  strip.Color(255,0,0),     // 红
  strip.Color(0,255,0),     // 绿
  strip.Color(0,0,255),     // 蓝
  strip.Color(255,255,0)    // 黄
};

void update_leds() {
  strip.setBrightness(brightness_table[brightness_mode]);
  uint32_t color = color_table[color_mode];
  for (int i = 0; i < NUM_LEDS; i++) {
    strip.setPixelColor(i, led_on ? color : 0);
  }
  strip.show();
}

class MyAdvertisedDeviceCallbacks : public BLEAdvertisedDeviceCallbacks {
    void onResult(BLEAdvertisedDevice advertisedDevice) {
        // 打印所有设备名和UUID，便于调试
        Serial.print("发现设备: Name: ");
        Serial.print(advertisedDevice.getName().c_str());
        Serial.print(", Address: ");
        Serial.print(advertisedDevice.getAddress().toString().c_str());
        Serial.print(", ServiceUUIDs: ");
        if (advertisedDevice.haveServiceUUID()) {
            Serial.print(advertisedDevice.getServiceUUID().toString().c_str());
        }
        Serial.println();

        // 用Service UUID过滤
        if (advertisedDevice.haveServiceUUID() && advertisedDevice.isAdvertisingService(BLEUUID(SERVICE_UUID))) {
            myDevice = new BLEAdvertisedDevice(advertisedDevice);
            doConnect = true;
            BLEDevice::getScan()->stop();
        }
    }
};

class MyClientCallback : public BLEClientCallbacks {
    void onConnect(BLEClient* pclient) {
        Serial.println("已连接到BLE服务端");
    }
    void onDisconnect(BLEClient* pclient) {
        Serial.println("BLE断开连接，重新扫描...");
        connected = false;
        doConnect = false;
    }
};

static void notifyCallback(
  BLERemoteCharacteristic* pBLERemoteCharacteristic,
  uint8_t* pData,
  size_t length,
  bool isNotify) {
    String action = "";
    for (size_t i = 0; i < length; i++) action += (char)pData[i];
    action.trim();
    Serial.print("收到手势识别结果: ");
    Serial.println(action);

    if (action == "OO") {
      Serial.println("执行：开/关灯");
      led_on = !led_on;
      if (led_on) {
        color_mode = 0; // 每次开灯都重置为白色
      }
      update_leds();
    } else if (action == "W") {
      Serial.println("执行：切换颜色");
      color_mode = (color_mode + 1) % 5;
      update_leds();
    } else if (action == "slope") {
      Serial.println("执行：切换亮度");
      brightness_mode = (brightness_mode + 1) % 3;
      update_leds();
    }
}

void setup() {
    Serial.begin(115200);
    strip.begin();
    strip.show();
    strip.setBrightness(brightness_table[brightness_mode]);

    BLEDevice::init("");
    BLEScan* pBLEScan = BLEDevice::getScan();
    pBLEScan->setAdvertisedDeviceCallbacks(new MyAdvertisedDeviceCallbacks());
    pBLEScan->setActiveScan(true);
    pBLEScan->start(30, false);
}

void loop() {
    if (doConnect && !connected) {
        Serial.println("尝试连接到目标BLE设备...");
        BLEClient*  pClient  = BLEDevice::createClient();
        pClient->setClientCallbacks(new MyClientCallback());

        if (pClient->connect(myDevice)) {
            Serial.println("成功连接到WandBLE!");
            BLERemoteService* pRemoteService = pClient->getService(SERVICE_UUID);
            if (pRemoteService == nullptr) {
                Serial.println("未找到服务，断开...");
                pClient->disconnect();
                return;
            }
            pRemoteCharacteristic = pRemoteService->getCharacteristic(CHARACTERISTIC_UUID);
            if (pRemoteCharacteristic == nullptr) {
                Serial.println("未找到特征，断开...");
                pClient->disconnect();
                return;
            }
            if (pRemoteCharacteristic->canNotify()) {
                Serial.println("已订阅特征通知，等待数据...");
                pRemoteCharacteristic->registerForNotify(notifyCallback);
            } else {
                Serial.println("特征不支持Notify，断开...");
                pClient->disconnect();
                return;
            }
            connected = true;
        } else {
            Serial.println("连接失败，重新扫描...");
        }
        doConnect = false;
    }
    delay(100);
}
